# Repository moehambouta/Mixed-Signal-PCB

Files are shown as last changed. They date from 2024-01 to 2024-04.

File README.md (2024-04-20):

# Mixed Signal PCB Project

This repository contains all the source files for the Mixed Signal PCB Project, an endeavor to design and develop a PCB capable of signal generation and analysis within the audio band. The project is thoroughly documented through a series of blog posts available at [Mixed Signal PCB Project Blog](https://www.mohamedhambouta.com/article/36e01b97-5775-4c1d-bf0c-83d208441204).

## Repository Structure

- `Assembly` - Contains the bill of materials and assembly information.
- `Components` - Individual component files used in the design.
- `Gerber` - Gerber files necessary for PCB manufacturing.
- `Media` - Images and videos showcasing the PCB and its design process.
- `PCB` - The KiCAD PCB design file.
- `Schematics` - Schematic files for each section of the PCB design.

## Acknowledgments

Special thanks to Phil's Lab for their course, which significantly contributed to the knowledge and techniques applied in this project. Find the course details [here](https://phils-lab-shop.fedevel.education/itemDetail.html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).

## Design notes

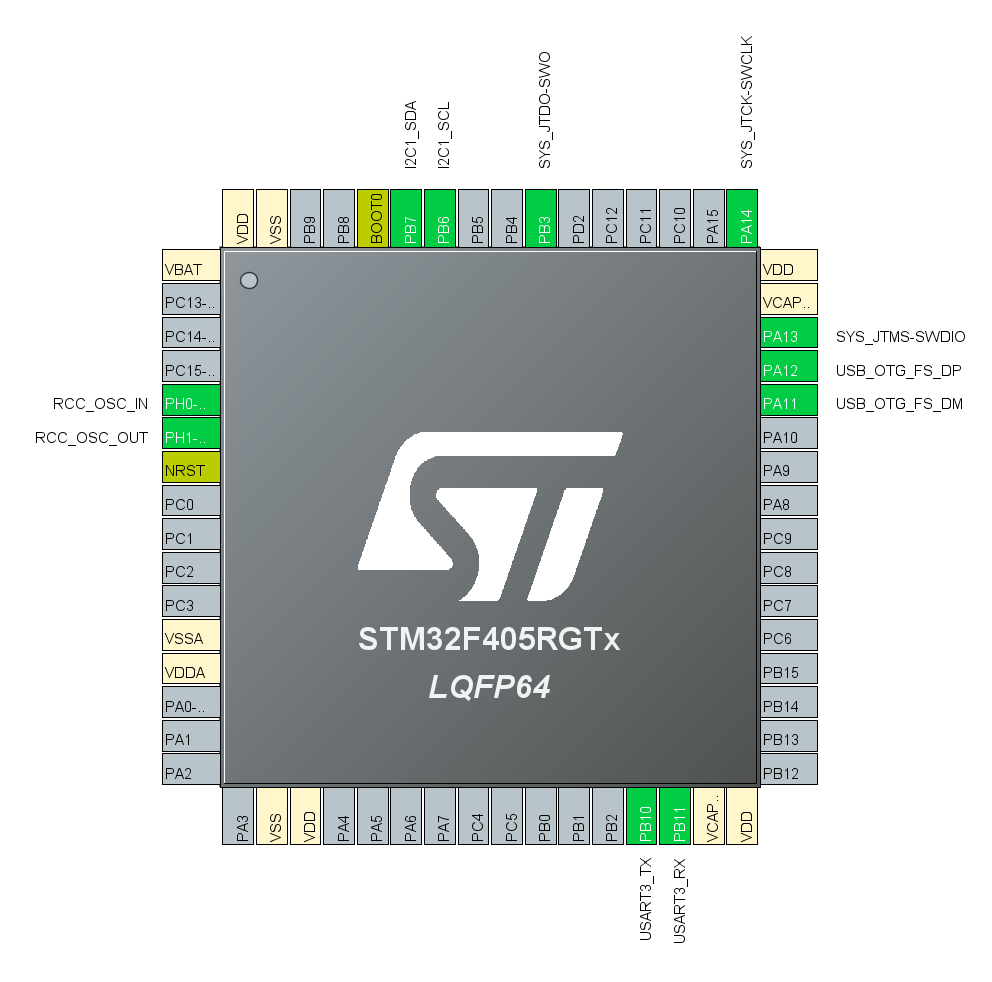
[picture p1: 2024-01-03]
Media/pinout.png

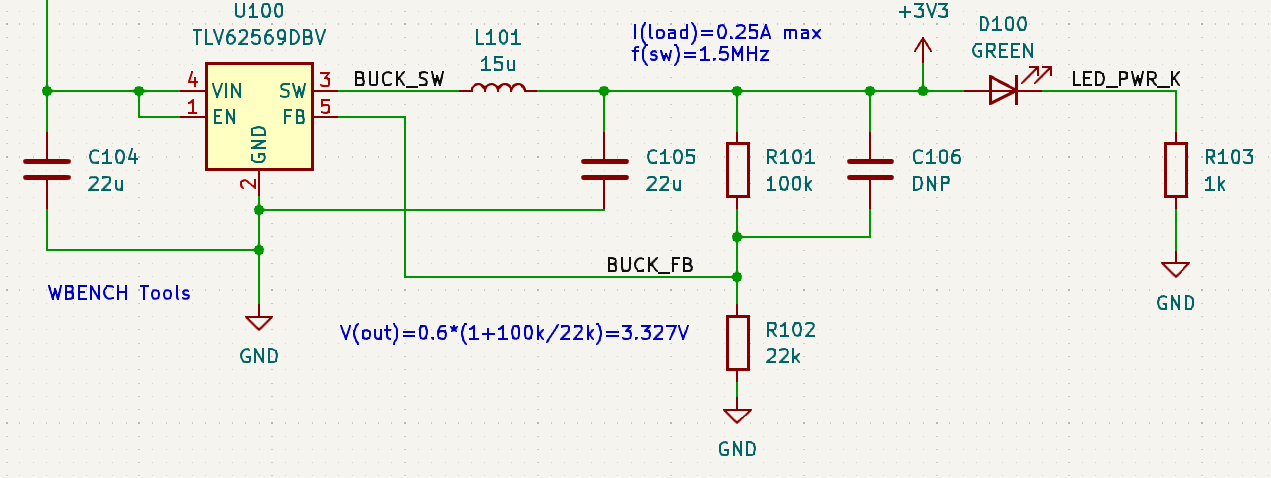
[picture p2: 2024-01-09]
Media/bc_schematic.png

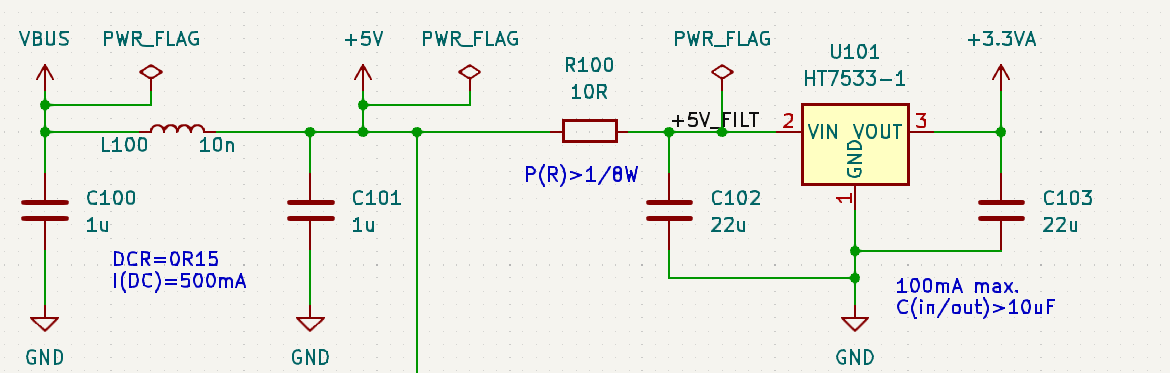
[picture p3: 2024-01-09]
Media/ldo_schematic.png

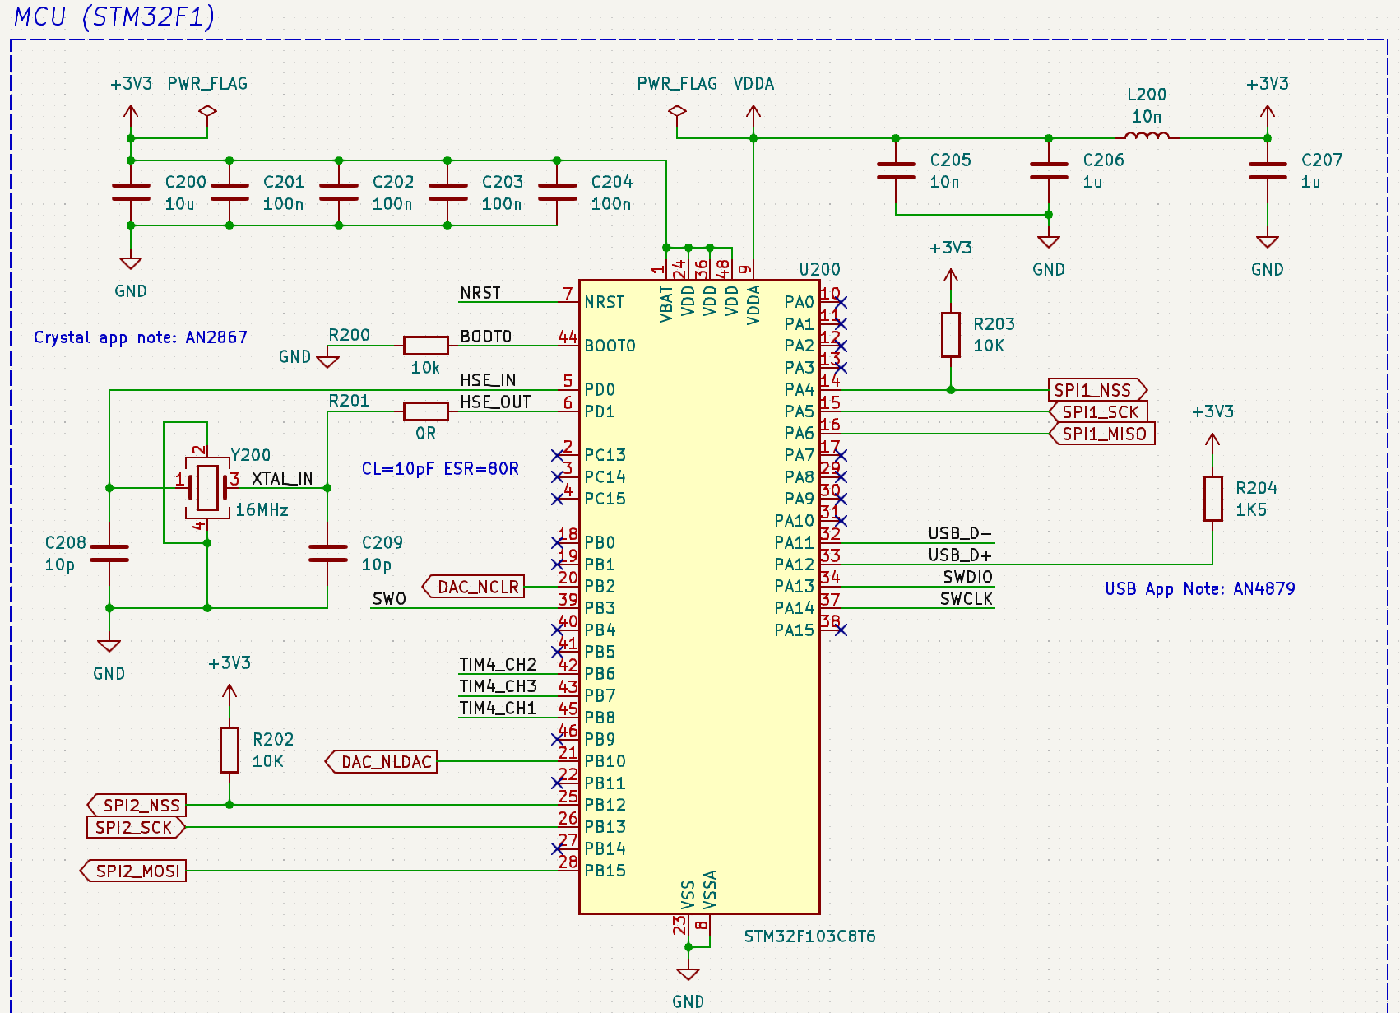
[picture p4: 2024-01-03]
.pages/assets/mcu.png

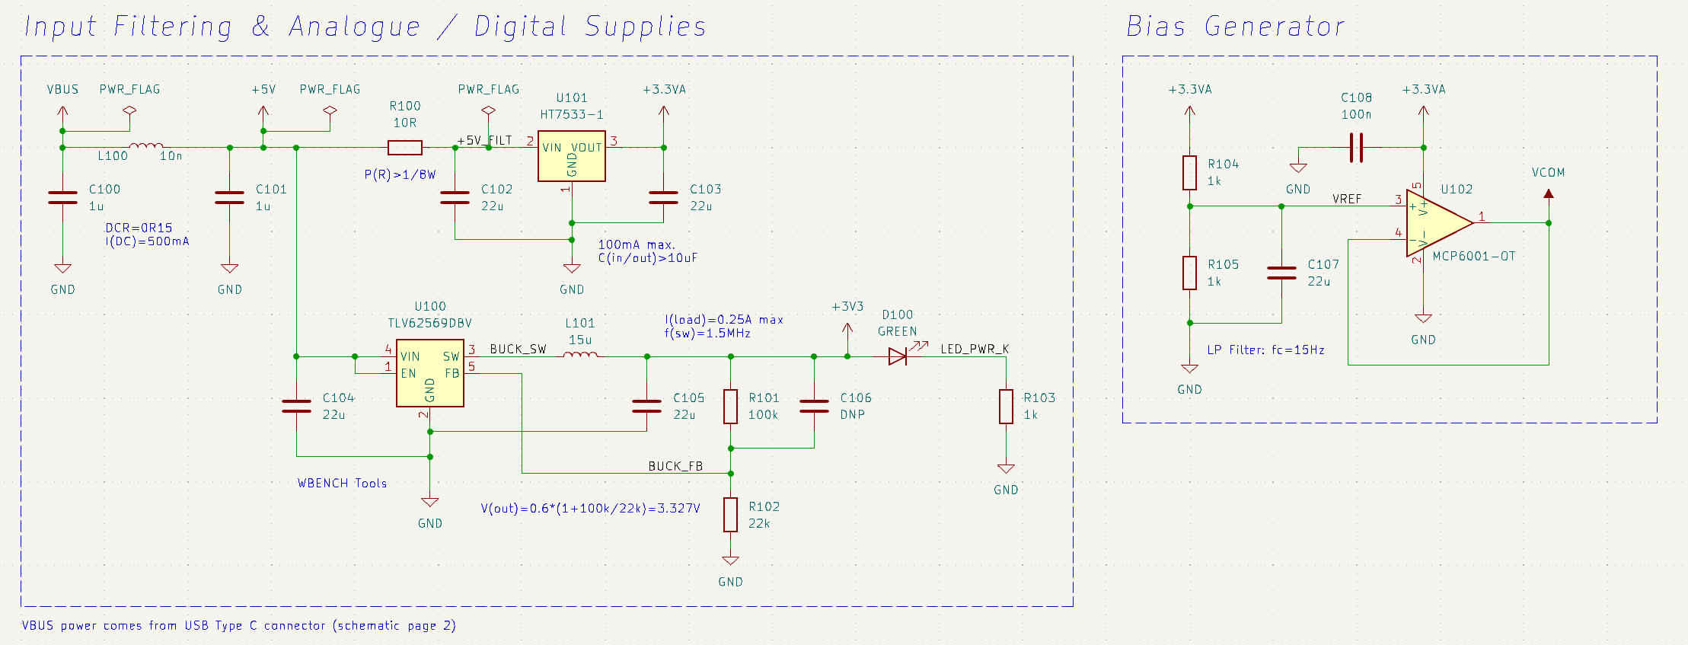
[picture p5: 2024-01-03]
.pages/assets/power.png

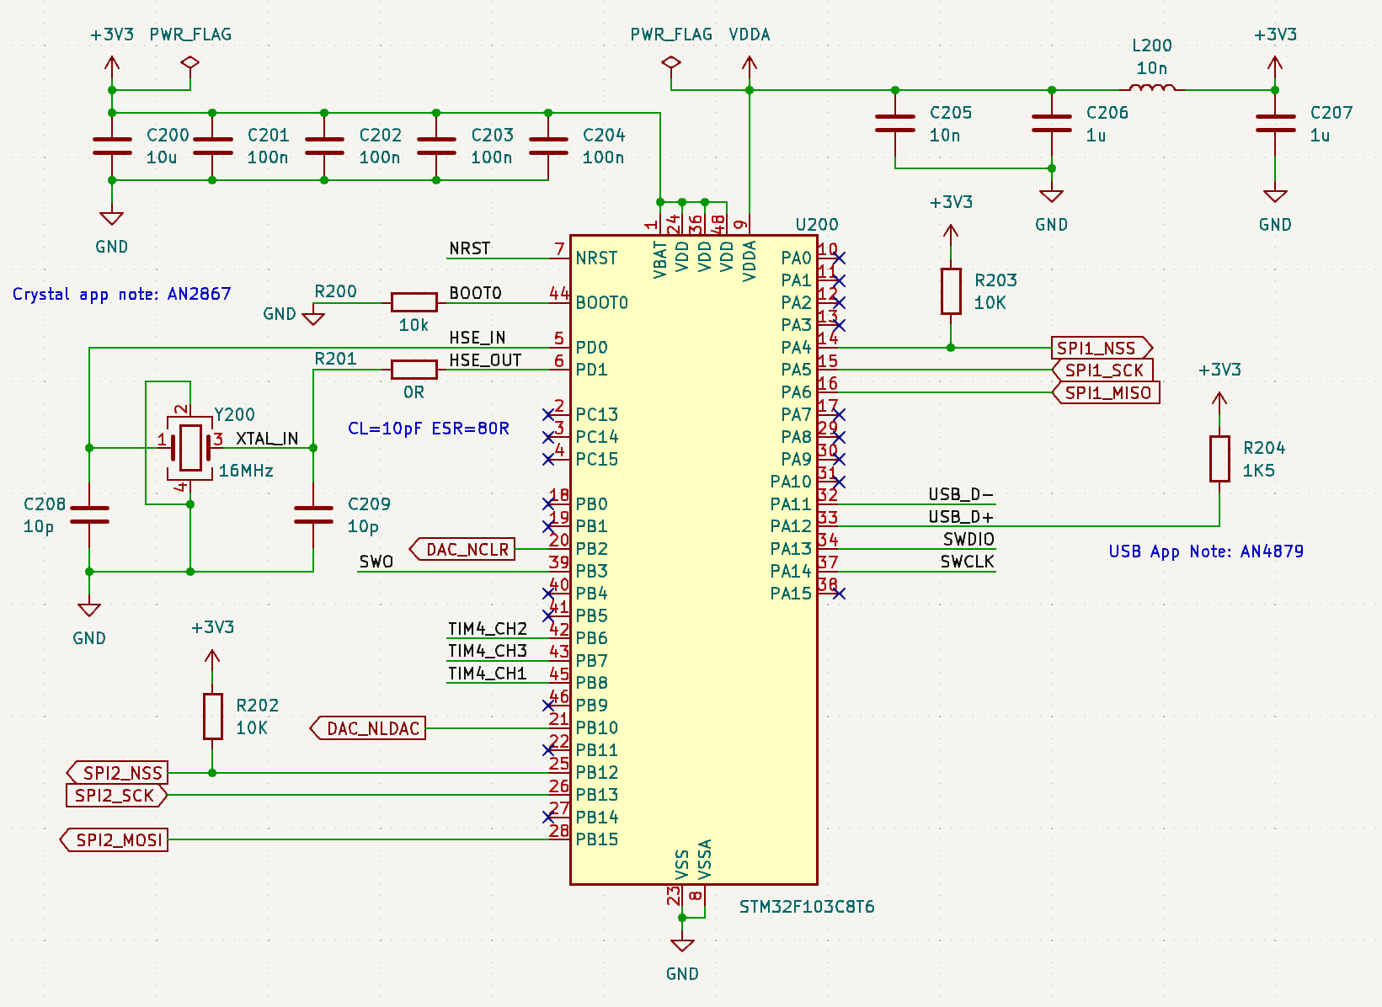
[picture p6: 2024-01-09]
Media/mcu.png

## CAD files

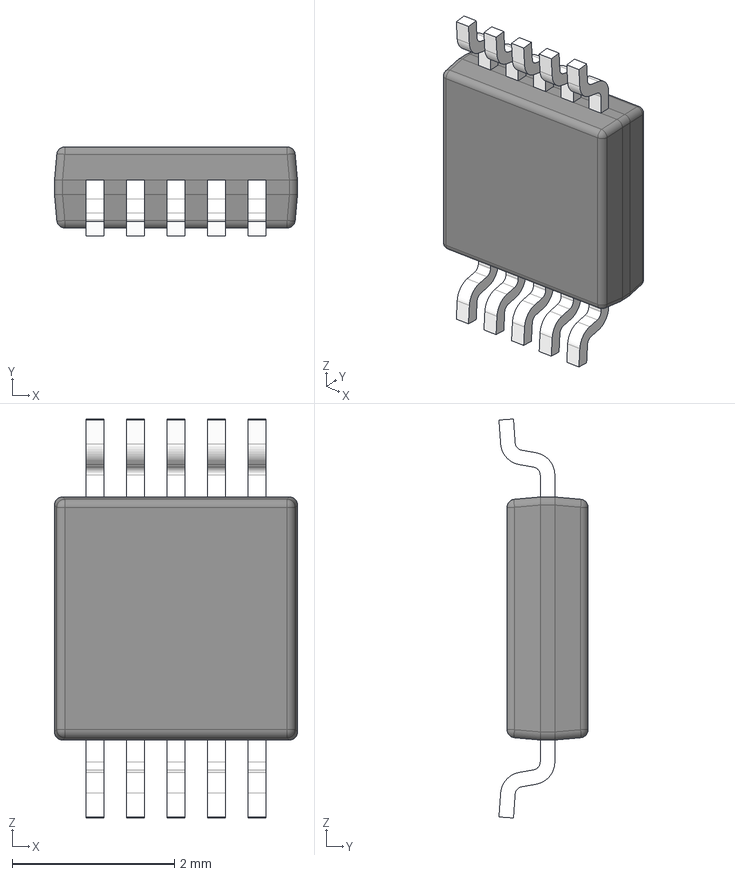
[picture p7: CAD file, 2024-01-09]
Components/DGS0010A.stp
3.00 x 1.10 x 4.93 mm
BODY-SO
LEAD-SO x 10
PIN1-ID

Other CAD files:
Components/User Library-DGS0010A.STEP

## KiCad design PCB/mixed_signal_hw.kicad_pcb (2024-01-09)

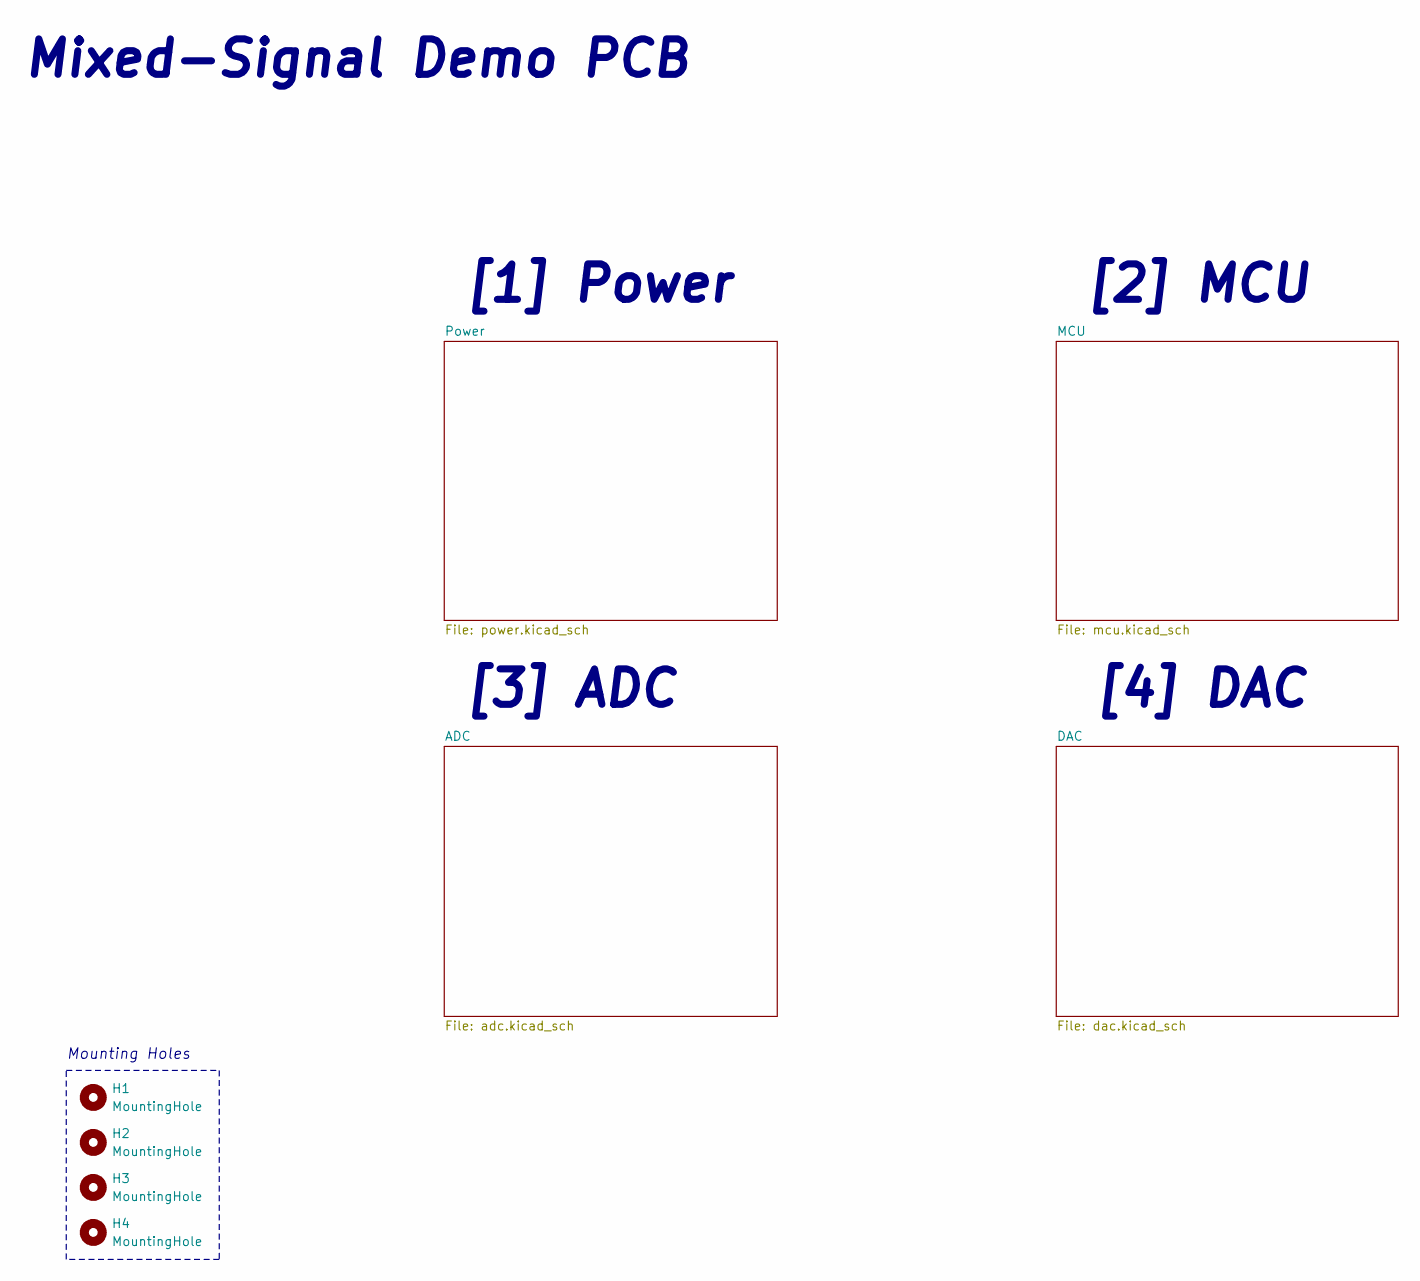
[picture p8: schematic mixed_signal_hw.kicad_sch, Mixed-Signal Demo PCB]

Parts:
H1, H2, H3, H4: MountingHole; MountingHole_3.2mm_M3

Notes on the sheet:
Mounting Holes
[4] DAC
[1] Power
[3] ADC
[2] MCU
Mixed-Signal Demo PCB

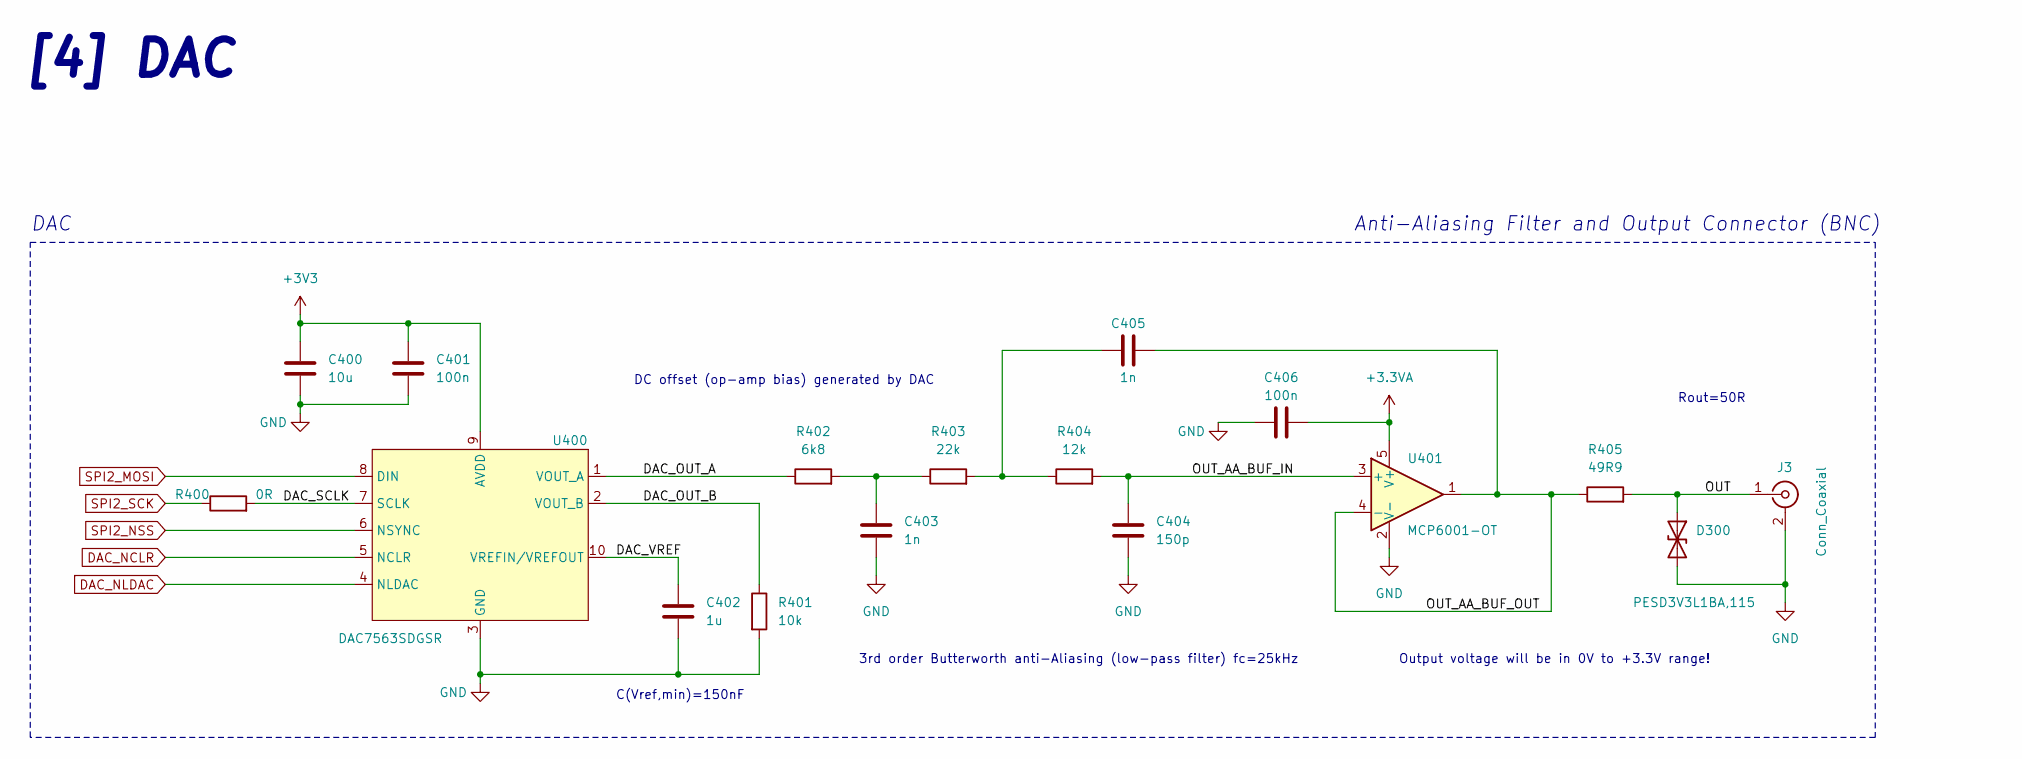
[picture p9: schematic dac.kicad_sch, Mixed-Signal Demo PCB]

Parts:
C400: 10u; C_0603_1608Metric
C401, C406: 100n; C_0402_1005Metric
C402: 1u; C_0603_1608Metric
C403, C405: 1n; C_0402_1005Metric
C404: 150p; C_0402_1005Metric
D300: PESD3V3L1BA,115; D_SOD-323
J3: Conn_Coaxial; AMPHENOL-BNC-031-5640-1010
R400: 0R; R_0402_1005Metric
R401: 10k; R_0402_1005Metric
R402: 6k8; R_0402_1005Metric
R403: 22k; R_0402_1005Metric
R404: 12k; R_0402_1005Metric
R405: 49R9; R_0402_1005Metric
U400: DAC7563SDGSR; VSSOP-10
U401: MCP6001-OT; SOT-23-5

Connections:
+3.3VA: C406.2, U401.5 (V+); also elsewhere on the board
+3V3: C400.1, C401.1, U400.9 (AVDD); also elsewhere on the board
/DAC/DAC_OUT_A: R402.1, U400.1 (VOUT_A)
/DAC/DAC_OUT_B: R401.1, U400.2 (VOUT_B)
/DAC/DAC_SCLK: R400.2, U400.7 (SCLK)
/DAC/DAC_VREF: C402.1, U400.10 (VREFIN/VREFOUT)
/DAC/OUT_AA_BUF_IN: C404.1, R404.2, U401.3 (+)
/DAC/OUT_AA_BUF_OUT: C405.2, R405.1, U401.1, U401.4 (-)
DAC_NCLR: U400.5 (NCLR); also elsewhere on the board
DAC_NLDAC: U400.4 (NLDAC); also elsewhere on the board
unnamed: C403.1, R402.2, R403.1
unnamed: C405.1, R403.2, R404.1
SPI2_MOSI: U400.8 (DIN); also elsewhere on the board
SPI2_NSS: U400.6 (NSYNC); also elsewhere on the board
SPI2_SCK: R400.1; also elsewhere on the board

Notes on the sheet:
Output voltage will be in 0V to +3.3V range!
Anti-Aliasing Filter and Output Connector (BNC)
3rd order Butterworth anti-Aliasing (low-pass filter) fc=25kHz
DAC
C(Vref,min)=150nF
DC offset (op-amp bias) generated by DAC
[4] DAC
Rout=50R

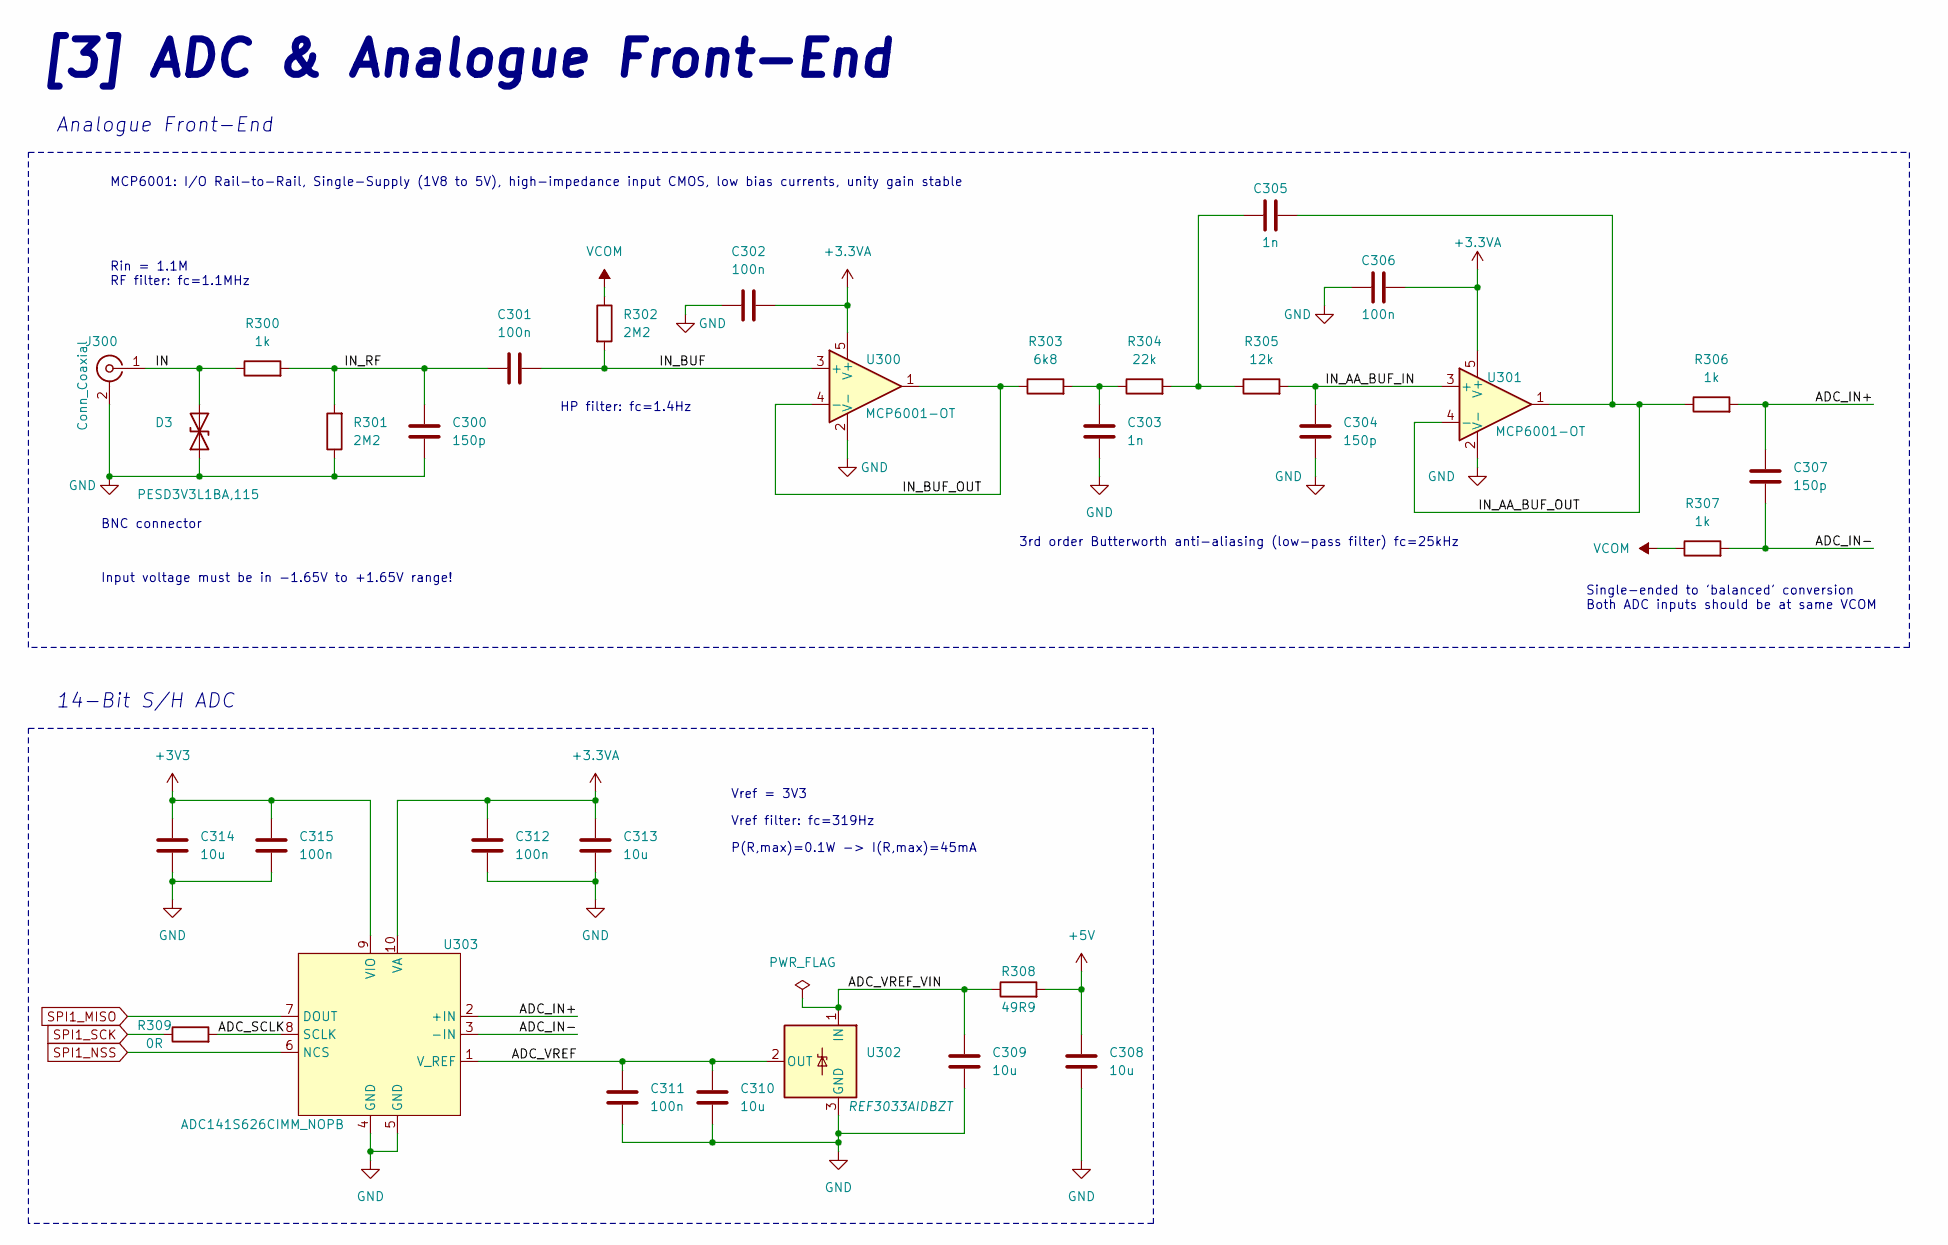
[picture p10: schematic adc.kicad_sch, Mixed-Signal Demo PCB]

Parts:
C300, C304, C307: 150p; C_0402_1005Metric
C301, C302, C306, C312, C315: 100n; C_0402_1005Metric
C303, C305: 1n; C_0402_1005Metric
C308, C309, C313, C314: 10u; C_0603_1608Metric
C310: 10u; C_0402_1005Metric
C311: 100n; C_0603_1608Metric
D3: PESD3V3L1BA,115; D_SOD-323
J300: Conn_Coaxial; AMPHENOL-BNC-031-5640-1010
R300, R306, R307: 1k; R_0402_1005Metric
R301, R302: 2M2; R_0402_1005Metric
R303: 6k8; R_0402_1005Metric
R304: 22k; R_0402_1005Metric
R305: 12k; R_0402_1005Metric
R308: 49R9; R_0402_1005Metric
R309: 0R; R_0402_1005Metric
U300, U301: MCP6001-OT; SOT-23-5
U302: REF3033AIDBZT; SOT-23
U303: ADC141S626CIMM_NOPB; VSSOP-10

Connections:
+3.3VA: C302.2, C306.1, C312.1, C313.1, U300.5 (V+), U301.5 (V+), U303.10 (VA); also elsewhere on the board
+3V3: C314.1, C315.1, U303.9 (VIO); also elsewhere on the board
+5V: C308.1, R308.2; also elsewhere on the board
/ADC/ADC_IN+: C307.1, R306.2, U303.2 (+IN)
/ADC/ADC_IN-: C307.2, R307.2, U303.3 (-IN)
/ADC/ADC_SCLK: R309.2, U303.8 (SCLK)
/ADC/ADC_VREF: C310.1, C311.1, U302.2 (OUT), U303.1 (V_REF)
/ADC/ADC_VREF_VIN: C309.1, R308.1, U302.1 (IN)
/ADC/IN_AA_BUF_IN: C304.1, R305.2, U301.3 (+)
/ADC/IN_AA_BUF_OUT: C305.1, R306.1, U301.1, U301.4 (-)
/ADC/IN_BUF: C301.2, R302.2, U300.3 (+)
/ADC/IN_BUF_OUT: R303.1, U300.1, U300.4 (-)
/ADC/IN_RF: C300.1, C301.1, R300.2, R301.2
unnamed: C303.1, R303.2, R304.1
unnamed: C305.2, R304.2, R305.1
SPI1_MISO: U303.7 (DOUT); also elsewhere on the board
SPI1_NSS: U303.6 (NCS); also elsewhere on the board
SPI1_SCK: R309.1; also elsewhere on the board
VCOM: R302.1, R307.1; also elsewhere on the board

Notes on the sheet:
HP filter: fc=1.4Hz
Single-ended to 'balanced' conversion Both ADC inputs should be at same VCOM
Vref filter: fc=319Hz
Rin = 1.1M RF filter: fc=1.1MHz
Vref = 3V3
Input voltage must be in -1.65V to +1.65V range!
3rd order Butterworth anti-aliasing (low-pass filter) fc=25kHz
MCP6001: I/O Rail-to-Rail, Single-Supply (1V8 to 5V), high-impedance input CMOS, low bias currents, unity gain stable
Analogue Front-End
BNC connector
14-Bit S/H ADC
[3] ADC & Analogue Front-End
P(R,max)=0.1W -> I(R,max)=45mA

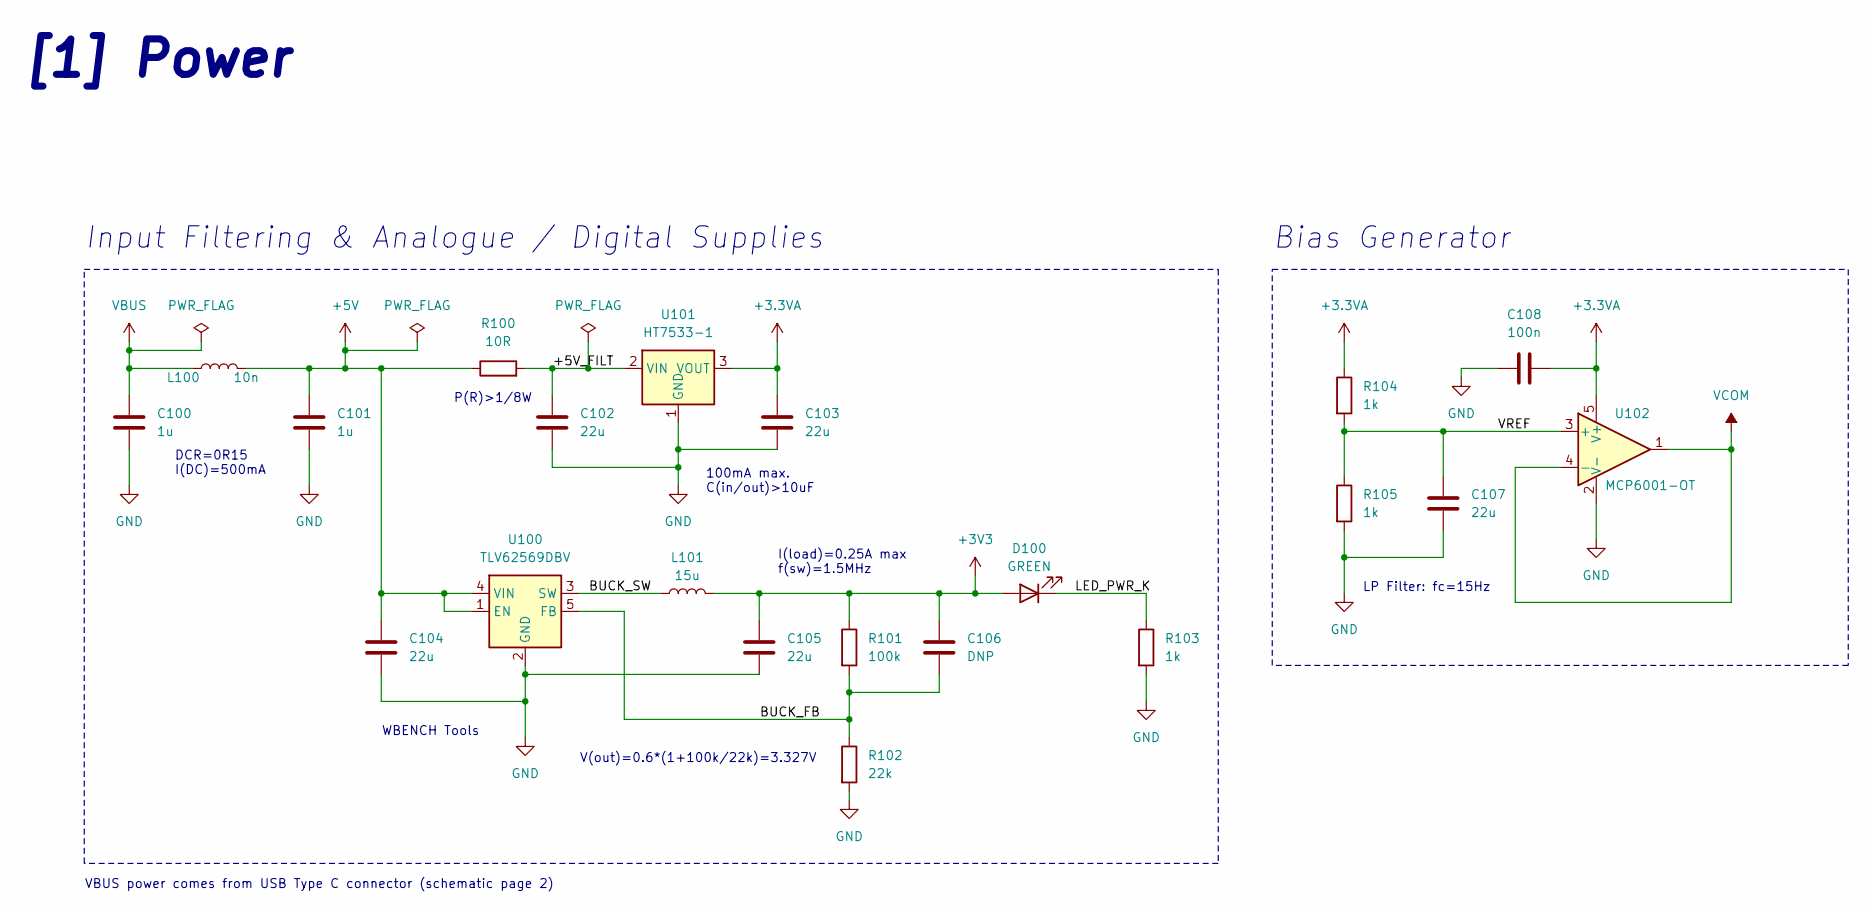
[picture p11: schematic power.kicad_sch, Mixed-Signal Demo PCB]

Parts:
C100, C101: 1u; C_0603_1608Metric
C102, C103, C104, C105, C107: 22u; C_0805_2012Metric
C106: DNP; C_0402_1005Metric
C108: 100n; C_0402_1005Metric
D100: GREEN; LED_0603_1608Metric
L100: 10n; L_0402_1005Metric
L101: 15u; MWSA0603S
R100: 10R; R_0805_2012Metric
R101: 100k; R_0402_1005Metric
R102: 22k; R_0402_1005Metric
R103, R104, R105: 1k; R_0402_1005Metric
U100: TLV62569DBV; SOT-23-5
U101: HT7533-1; SOT-89-3
U102: MCP6001-OT; SOT-23-5

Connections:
+3.3VA: C103.1, C108.2, R104.1, U101.3 (VOUT), U102.5 (V+); also elsewhere on the board
+3V3: C105.1, C106.1, D100.2 (A), L101.2, R101.1; also elsewhere on the board
+5V: C101.1, C104.1, L100.2, R100.1, U100.1 (EN), U100.4 (VIN); also elsewhere on the board
/Power/+5V_FILT: C102.1, R100.2, U101.2 (VIN)
/Power/BUCK_FB: C106.2, R101.2, R102.1, U100.5 (FB)
/Power/BUCK_SW: L101.1, U100.3 (SW)
/Power/LED_PWR_K: D100.1 (K), R103.1
/Power/VREF: C107.1, R104.2, R105.1, U102.3 (+)
VBUS: C100.1, L100.1; also elsewhere on the board
VCOM: U102.1, U102.4 (-); also elsewhere on the board

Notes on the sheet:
P(R)>1/8W
LP Filter: fc=15Hz
Bias Generator
DCR=0R15 I(DC)=500mA
VBUS power comes from USB Type C connector (schematic page 2)
Input Filtering & Analogue / Digital Supplies
I(load)=0.25A max f(sw)=1.5MHz
[1] Power
V(out)=0.6*(1+100k/22k)=3.327V
WBENCH Tools
100mA max. C(in/out)>10uF

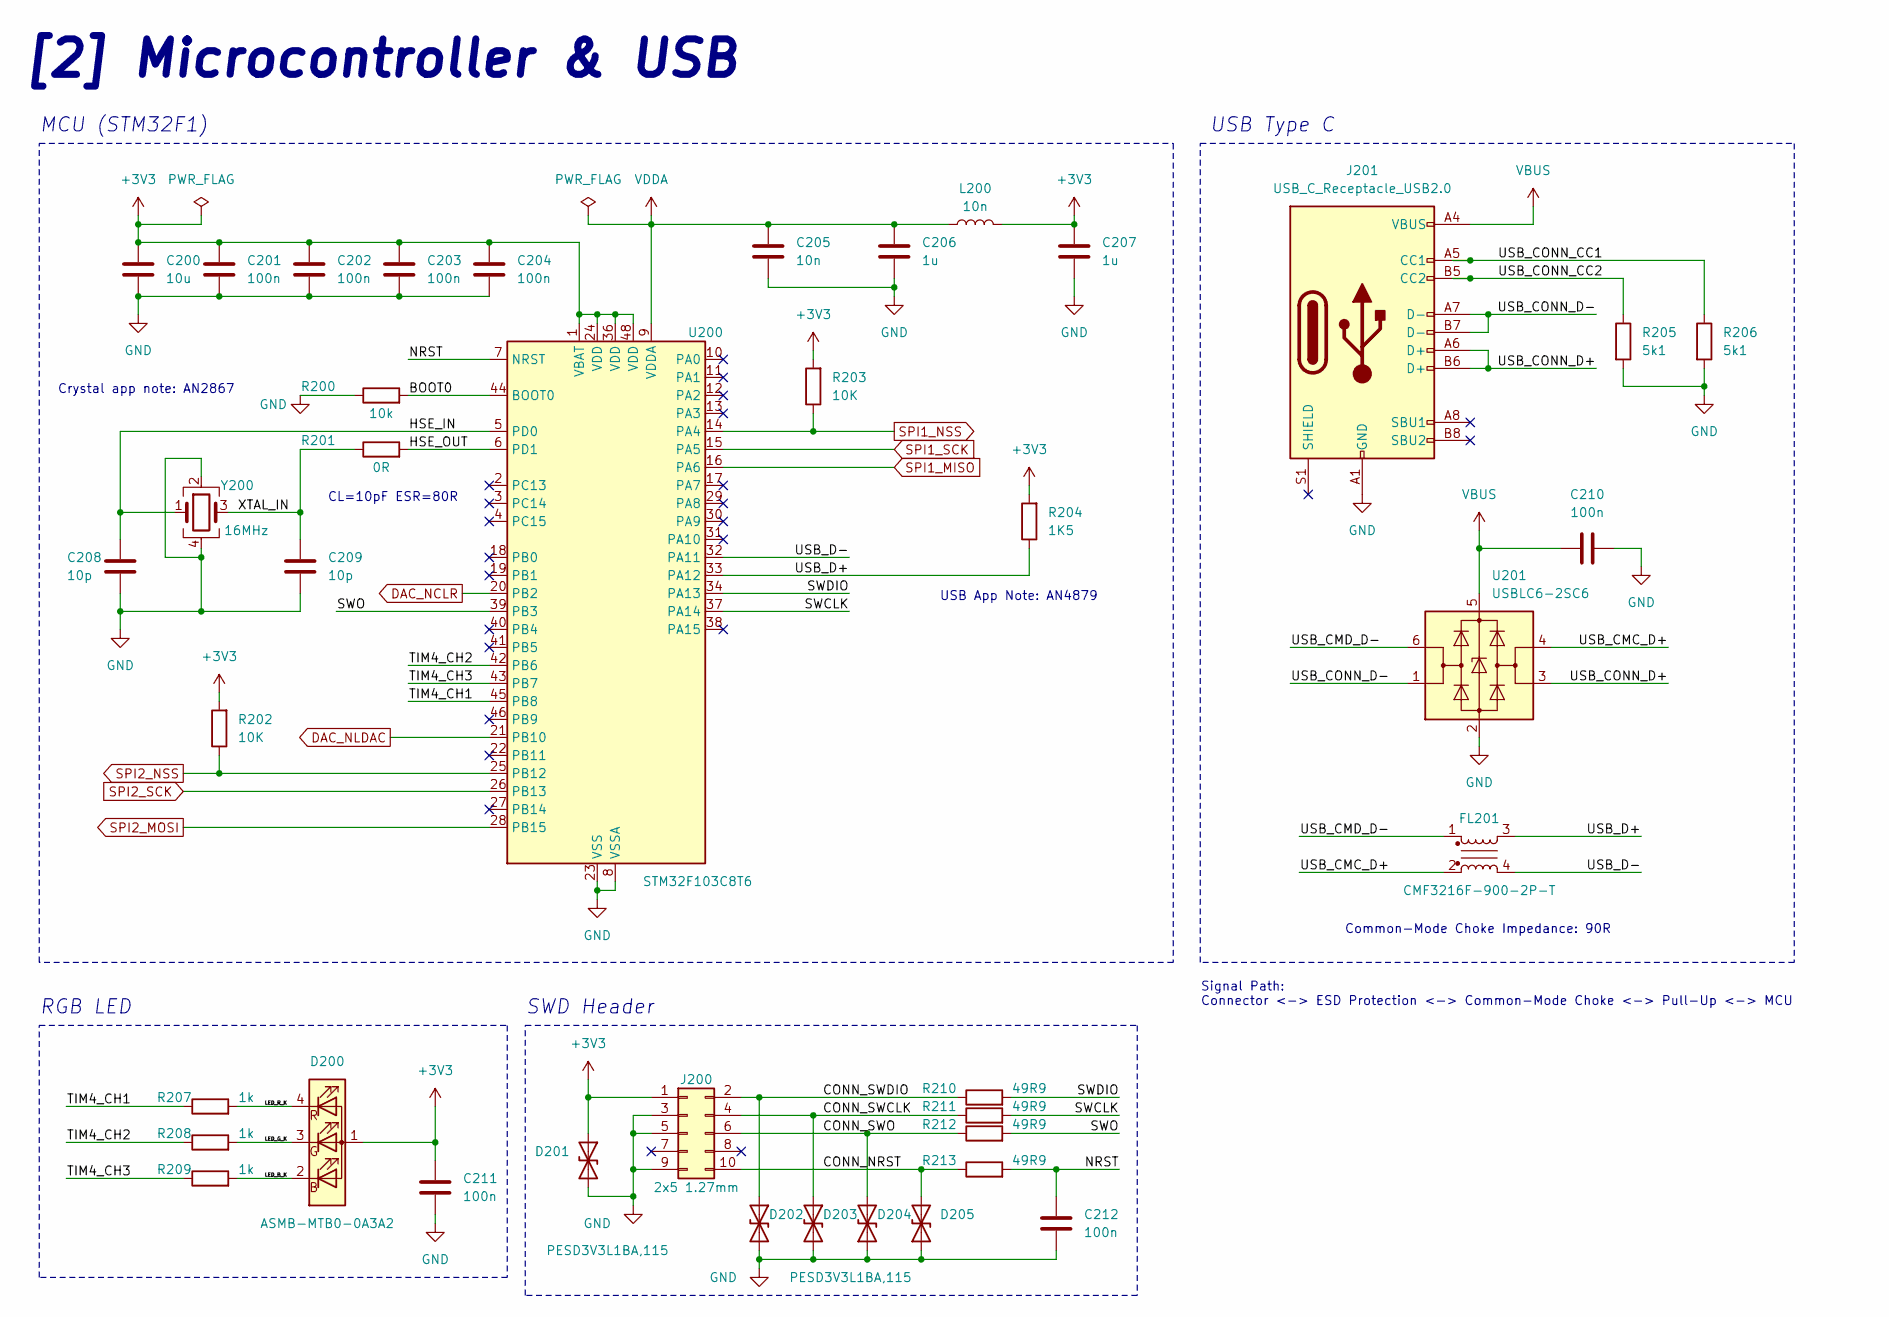
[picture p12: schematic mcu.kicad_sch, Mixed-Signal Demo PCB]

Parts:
C200: 10u; C_0603_1608Metric
C201, C202, C203, C204, C210, C211, C212: 100n; C_0402_1005Metric
C205: 10n; C_0402_1005Metric
C206, C207: 1u; C_0603_1608Metric
C208, C209: 10p; C_0402_1005Metric
D200: ASMB-MTB0-0A3A2; LED_Avago_PLCC4_3.2x2.8mm_CW
D201, D202, D203, D204, D205: PESD3V3L1BA,115; D_SOD-323
FL201: CMF3216F-900-2P-T; CMC-1206
J200: 2x5 1.27mm; PinHeader_2x05_P1.27mm_Vertical_SMD
J201: USB_C_Receptacle_USB2.0; USB_C_Receptacle_HRO_TYPE-C-31-M-12
L200: 10n; L_0402_1005Metric
R200: 10k; R_0402_1005Metric
R201: 0R; R_0402_1005Metric
R202, R203: 10K; R_0402_1005Metric
R204: 1K5; R_0402_1005Metric
R205, R206: 5k1; R_0402_1005Metric
R207, R208, R209: 1k; R_0402_1005Metric
R210, R211, R212, R213: 49R9; R_0402_1005Metric
U200: STM32F103C8T6; LQFP-48_7x7mm_P0.5mm
U201: USBLC6-2SC6; SOT-23-6
Y200: 16MHz; Crystal_SMD_3225-4Pin_3.2x2.5mm

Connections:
+3V3: C200.1, C201.1, C202.1, C203.1, C204.1, C207.1, C211.1, D200.1 (A), D201.1 (A1), J200.1, L200.2, R202.2, R203.2, R204.2, U200.1 (VBAT), U200.24 (VDD), U200.36 (VDD), U200.48 (VDD); also elsewhere on the board
/MCU/BOOT0: R200.2, U200.44 (BOOT0)
/MCU/CONN_NRST: D205.2 (A2), J200.10, R213.1
/MCU/CONN_SWCLK: D203.1 (A1), J200.4, R211.1
/MCU/CONN_SWDIO: D202.1 (A1), J200.2, R210.1
/MCU/CONN_SWO: D204.2 (A2), J200.6, R212.1
/MCU/HSE_IN: C208.1, U200.5 (PD0), Y200.1
/MCU/HSE_OUT: R201.2, U200.6 (PD1)
/MCU/LED_B_K: D200.2 (BK), R209.2
/MCU/LED_G_K: D200.3 (GK), R208.2
/MCU/LED_R_K: D200.4 (RK), R207.2
/MCU/NRST: C212.1, R213.2, U200.7 (NRST)
/MCU/SWCLK: R211.2, U200.37 (PA14)
/MCU/SWDIO: R210.2, U200.34 (PA13)
/MCU/SWO: R212.2, U200.39 (PB3)
/MCU/TIM4_CH1: R207.1, U200.45 (PB8)
/MCU/TIM4_CH2: R208.1, U200.42 (PB6)
/MCU/TIM4_CH3: R209.1, U200.43 (PB7)
/MCU/USB_CMC_D+: FL201.2, U201.4 (I/O2)
/MCU/USB_CMD_D-: FL201.1, U201.6 (I/O1)
/MCU/USB_CONN_CC1: J201.A5 (CC1), R206.1
/MCU/USB_CONN_CC2: J201.B5 (CC2), R205.1
/MCU/USB_CONN_D+: J201.A6 (D+), J201.B6 (D+), U201.3 (I/O2)
/MCU/USB_CONN_D-: J201.A7 (D-), J201.B7 (D-), U201.1 (I/O1)
/MCU/USB_D+: FL201.3, R204.1, U200.33 (PA12)
/MCU/USB_D-: FL201.4, U200.32 (PA11)
/MCU/XTAL_IN: C209.1, R201.1, Y200.3
DAC_NCLR: U200.20 (PB2); also elsewhere on the board
DAC_NLDAC: U200.21 (PB10); also elsewhere on the board
SPI1_MISO: U200.16 (PA6); also elsewhere on the board
SPI1_NSS: R203.1, U200.14 (PA4); also elsewhere on the board
SPI1_SCK: U200.15 (PA5); also elsewhere on the board
SPI2_MOSI: U200.28 (PB15); also elsewhere on the board
SPI2_NSS: R202.1, U200.25 (PB12); also elsewhere on the board
SPI2_SCK: U200.26 (PB13); also elsewhere on the board
VBUS: C210.1, J201.A4 (VBUS), J201.A9 (VBUS), J201.B4 (VBUS), J201.B9 (VBUS), U201.5 (VBUS); also elsewhere on the board
VDDA: C205.1, C206.1, L200.1, U200.9 (VDDA)

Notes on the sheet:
Common-Mode Choke Impedance: 90R
Crystal app note: AN2867
RGB LED
[2] Microcontroller & USB
USB App Note: AN4879
CL=10pF ESR=80R
MCU (STM32F1)
SWD Header
Signal Path: Connector <-> ESD Protection <-> Common-Mode Choke <-> Pull-Up <-> MCU
USB Type C

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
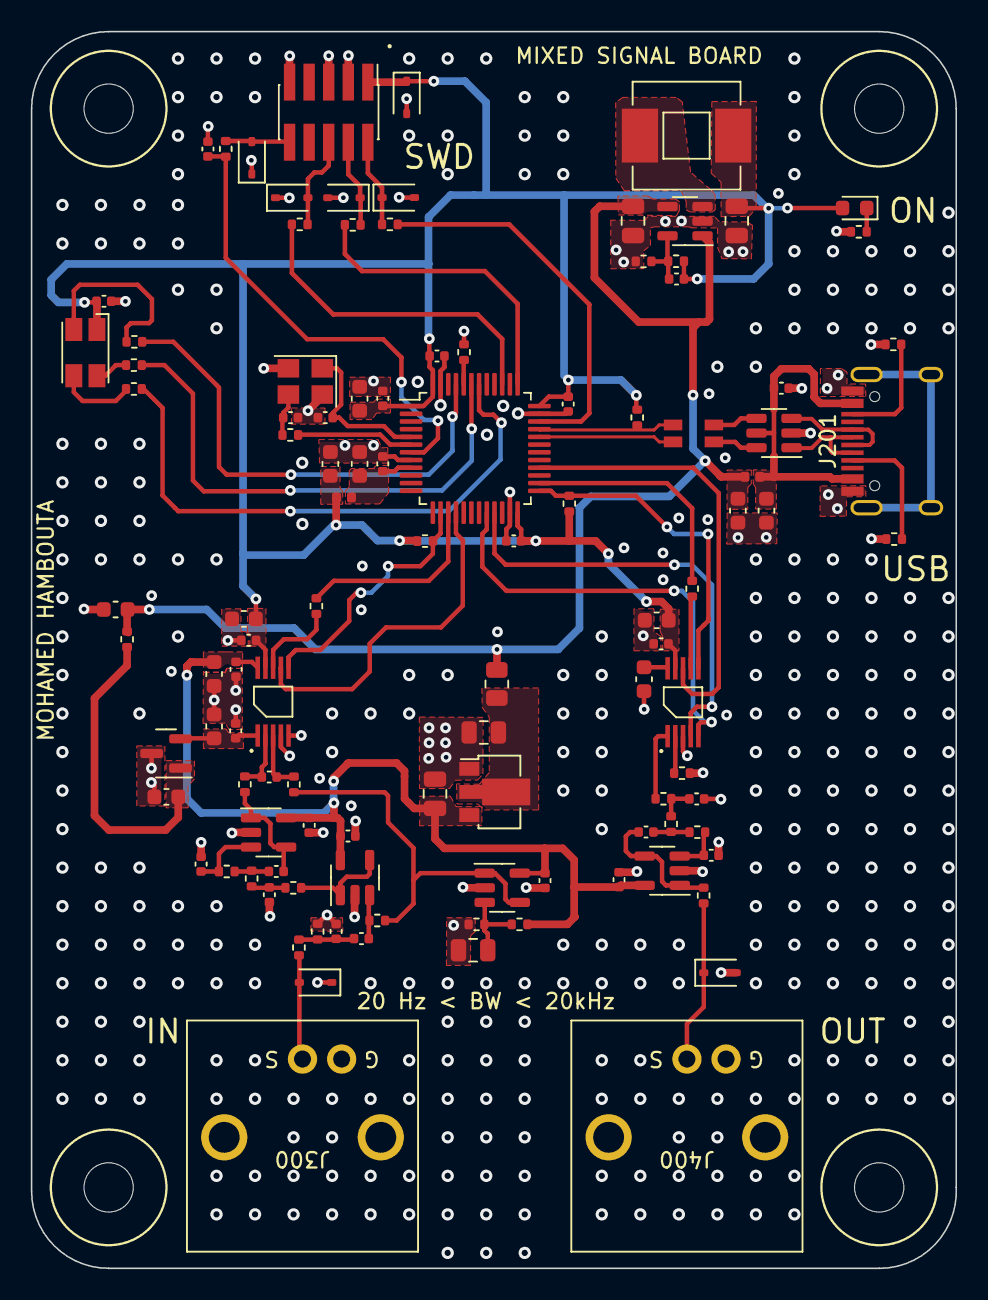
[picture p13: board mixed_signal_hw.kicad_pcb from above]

Board: 4 copper layers, 60.0 x 80.3 mm, 114 parts (0 on the bottom side), 68 nets.

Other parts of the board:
D400: PESD3V3L1BA,115; D_SOD-323
J400: Conn_Coaxial; AMPHENOL-BNC-031-5640-1010
